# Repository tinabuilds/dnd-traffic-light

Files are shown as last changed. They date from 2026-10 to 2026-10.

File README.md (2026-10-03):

# Do Not Disturb Desk Traffic Light

A small 3D-printed traffic light that sits on my desk and tells the people at home whether they can come talk to me.

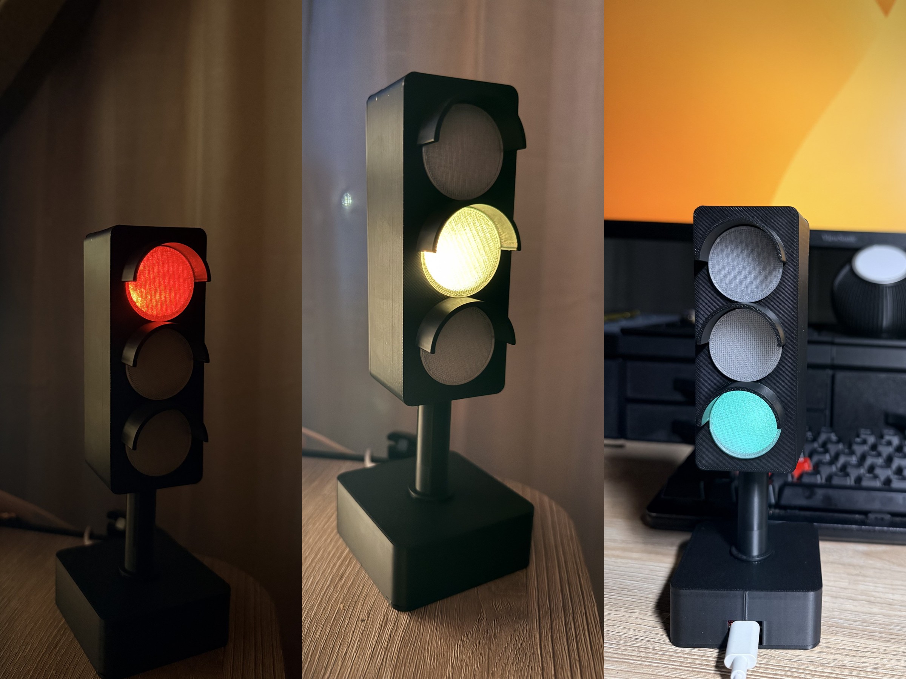
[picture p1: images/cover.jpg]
Red, yellow and green


| Color | Meaning |
|---|---|
| 🔴 Red | On a call, or audio is playing in my headphones. Don't come in. |
| 🟡 Yellow | In a focus block. Interrupt only if it matters. Blinks in the last 5 minutes. |
| 🟢 Green | Come find me. |
| Off | I'm away from the computer. |

The light only shows what the other person *can't* see. Just sitting at the computer isn't yellow, because they can see that.

## How it works

The board doesn't make any decisions. The computer works out the color and sends one letter over USB serial, about once a second:

| Letter | Effect |
|---|---|
| `R` | red |
| `Y` | yellow |
| `B` | blinking yellow |
| `G` | green |
| `O` | off |
| `?` | board replies `traffic-light` (to find the right serial port) |

If nothing arrives for 15 seconds, the light turns itself off. That way it never gets stuck on an old color when the laptop sleeps or the cable comes out.

Because all the rules live on the computer, you can change them without reflashing.

### The rules I use (checked in order)

1. **Red**: manual red (keyboard shortcut), the microphone is in use (dictation apps don't count), or real sound is coming out of the headphones
2. **Off**: no keyboard or mouse input for 5 minutes
3. **Yellow**: inside a focus block (a Google Calendar Focus Time event, or one started from a shortcut)
4. **Green**: everything else

My own sender script is tied to my personal setup, so it isn't here. The protocol is simple enough that a few lines will drive the light:

```python
# pip install pyserial
import serial, time
port = serial.Serial("/dev/cu.usbmodem1101", 115200)   # your port will differ
while True:
    port.write(b"G")      # replace with your own logic
    time.sleep(1)
```

## Parts

- Seeed Studio XIAO ESP32-C3
- 5 LEDs of WS2812B strip, 60 LEDs/m, **one uncut piece** (LEDs 0 / 2 / 4 light green / yellow / red; 1 and 3 stay off)
- 3 short wires, USB-C cable
- Filament: clear PETG for the lenses, black PLA for the body

Wiring: strip DIN → **D1**, 5V → 5V, GND → GND. Don't use D0: it's a boot strapping pin, and a strip on it can stop the board from booting.

Thread the wires through the pole **before** you solder.

| Strip on the back cover | Strip going into the housing | XIAO soldered |
|---|---|---|
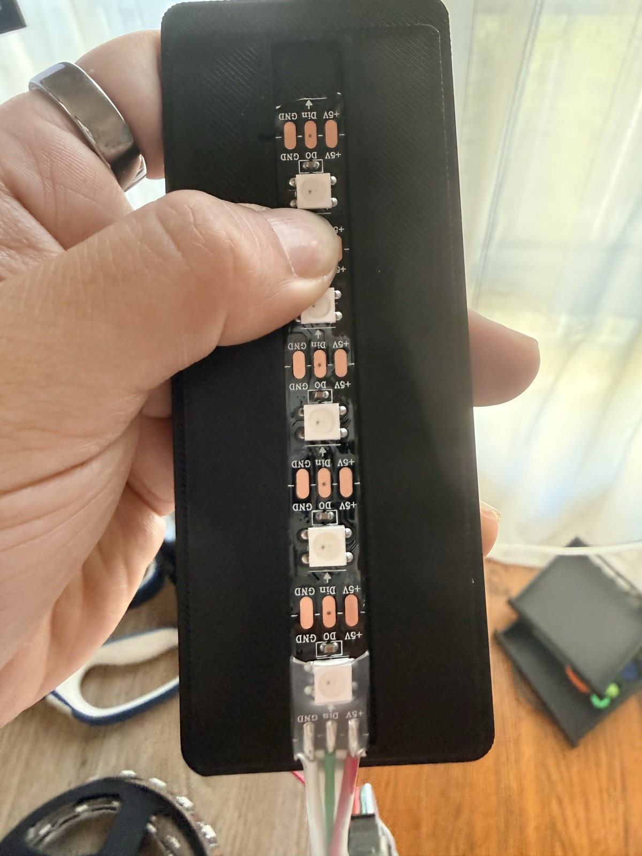
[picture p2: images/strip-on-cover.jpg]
Strip on the back cover
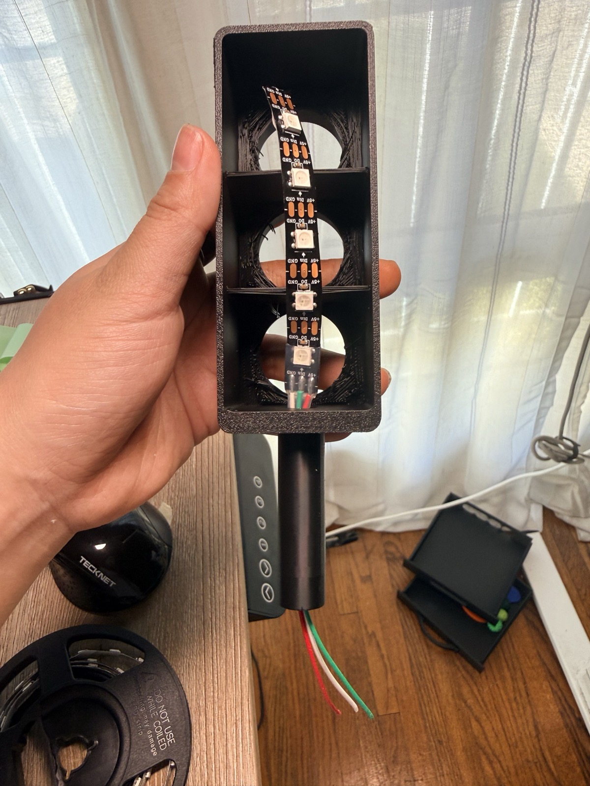
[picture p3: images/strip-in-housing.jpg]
Strip going into the housing
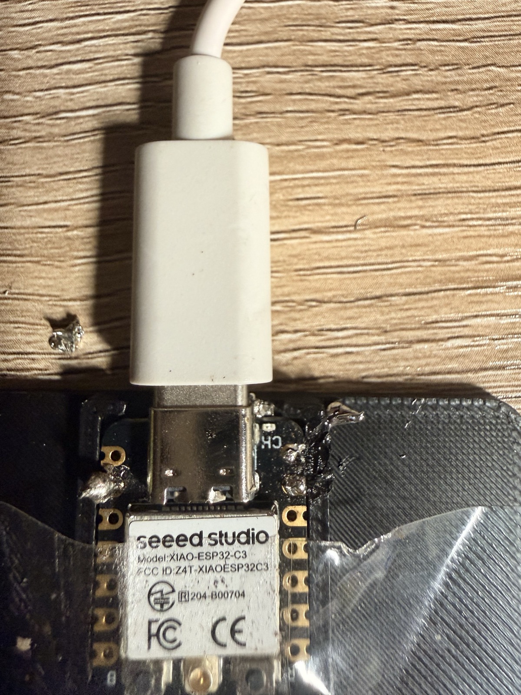
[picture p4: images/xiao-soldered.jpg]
XIAO soldered
|  |  |  |

The strip sits in a channel on the inside of the back cover, so the LEDs line up with the lenses on their own.

## Firmware

[`firmware/traffic_light_fw/traffic_light_fw.ino`](firmware/traffic_light_fw/traffic_light_fw.ino). Needs the Adafruit NeoPixel library.

```bash
arduino-cli compile --fqbn esp32:esp32:XIAO_ESP32C3 firmware/traffic_light_fw
arduino-cli upload  --fqbn esp32:esp32:XIAO_ESP32C3 -p <port> firmware/traffic_light_fw
```

On power-up it flashes green, yellow, red once, so you can check the LEDs line up.

## 3D model

[`cad/traffic_light.scad`](cad/traffic_light.scad) is the full OpenSCAD source. Export each part:

```bash
cd cad
for p in housing cover lenses pole base plate; do
  openscad -D "part=\"$p\"" -o "$p.stl" traffic_light.scad
done
```

No supports needed. Print the lenses in clear PETG and everything else in black PLA. The pole screws into the base; the other parts push in and hold on crush ribs, so no glue.

## License

[CC BY-NC 4.0](https://creativecommons.org/licenses/by-nc/4.0/) — free to build, remix and share with credit, as long as it is not for commercial use (no selling prints, kits or files).

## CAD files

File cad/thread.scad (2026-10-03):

// Single-start round thread: an off-center circle extruded with a twist.
// The same module makes the bolt and the hole; only the radius differs (hole = r + clearance per side).
// Tested: r = 8, offset 0.6 (1.2 mm thread depth), pitch 3, hole +0.3 per side. Prints standing, no supports.
module thread(r, l, e = 0.6, pitch = 3)
    linear_extrude(l, twist = -360 * l / pitch, slices = ceil(l / pitch * 36), convexity = 4)
        translate([e, 0]) circle(r = r - e, $fn = 64);

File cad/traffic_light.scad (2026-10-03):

// Mini desk traffic light for a WS2812B strip (60 LED/m) + Seeed XIAO ESP32-C3. Units: mm.
// Export: openscad -D 'part="housing"' -o housing.stl traffic_light.scad
// Parts: housing, cover, lenses, pole, base, plate, assembly (preview only)
//
// Joints (v2, after the first print came out loose):
//   pole -> base   screws in (same round thread as the scrunchie post, tested good); a collar on the pole stops it
//   pole -> housing, cover -> housing, plate -> base   push in and hold on crush ribs:
//     thin triangular ribs that squash on the way in, so the fit doesn't depend on hitting an exact clearance.
//     No printed snap bumps: two broke on the claw-clip rack.
//
// One uncut 5-LED piece of strip runs up the back cover. At 60 LED/m the pitch is
// 16.67 mm, so LEDs 0 / 2 / 4 land exactly on the three lenses; 1 and 3 stay off.

part = "assembly";

PITCH = 1000 / 60;
SP = 2 * PITCH;                  // lens spacing = 33.33
W = 44;  H = 112;  D = 34;       // housing outer (x, y, z); z = depth, front at z = D
WALL = 2;  FRONT = 2.4;  FLOOR = 6;  R = 4;
LENS_Y = [FLOOR + 16.67, FLOOR + 16.67 + SP, FLOOR + 16.67 + 2 * SP];
HOLE = 28;  LENS_D = 31;  LENS_T = 1.2;  FIT = 0.4;
VISOR_R = 17;  VISOR_T = 1.8;  VISOR_L = 12;
POLE_OD = 14;  POLE_ID = 9;  POLE_VIS = 43;  SOCKET = 5;  PFIT = 0.3;   // POLE_VIS = pole showing between collar and housing
THREAD_R = 8;  THREAD_E = 0.6;  THREAD_PITCH = 3;  THREAD_L = 10;  THREAD_FIT = 0.3;   // not PITCH: that name is the LED pitch above
COLLAR_D = 20;  COLLAR_H = 2;  BOSS_D = 24;
RIB = 0.35;      // how far a crush rib stands proud of the part's nominal surface (clearances here are 0.15 per side)
LIP = 3;         // cover lip depth into the housing. Keep LIP + LED height (~1.6) under the dividers' start (z = 6)
BW = 64;  BH = 24;  BWALL = 2.4;  BTOP = 3;  BR = 6;
PLATE_FL = 1.6;  PLATE_LIP = 3;   // bottom plate: flange under the base's bottom edge + lip that pushes in on crush ribs
XIAO = [21, 17.8];  USB_SLOT = [14, 11];   // cradle size checked on the print: XIAO drops in exactly
STRIP_W = 10.5;
$fn = 72;

use <thread.scad>

// crush rib: triangular, standing on a face that points along +x, height h along z, chamfered at the top
module rib(h) {
  hull() {
    translate([-0.2, -0.6, 0]) cube([0.2, 1.2, h]);
    translate([0, -0.01, 0]) cube([RIB, 0.02, h - 0.6]);
  }
}

module rbox(x, y, z, r) {             // rounded in the x-y plane, height z
  linear_extrude(z) offset(r) offset(-r) square([x, y], center = true);
}

// ---------- housing (print back-side down, visors pointing up) ----------
module housing() {
  difference() {
    union() {
      translate([0, H/2, 0]) rbox(W, H, D, R);
      for (y = LENS_Y) visor(y);
    }
    // hollow, open at the back
    translate([0, (H + FLOOR - WALL)/2, -1]) rbox(W - 2*WALL, H - FLOOR - WALL, D - FRONT + 1, R - WALL);
    for (y = LENS_Y) {
      translate([0, y, D - FRONT - 1]) cylinder(d = HOLE, h = FRONT + 2);
      translate([0, y, D - FRONT - 0.01]) cylinder(d = LENS_D + FIT, h = LENS_T + 0.01);
    }
    // pole socket in the thick floor, then wire hole into the housing
    translate([0, -1, D/2]) rotate([-90, 0, 0]) cylinder(d = POLE_OD + PFIT, h = SOCKET + 1);
    translate([0, 0, D/2]) rotate([-90, 0, 0]) cylinder(d = POLE_ID, h = FLOOR + 1);
  }
  // light dividers, stop short of the back so the strip can pass
  for (y = [(LENS_Y[0] + LENS_Y[1])/2, (LENS_Y[1] + LENS_Y[2])/2])
    translate([-(W - 2*WALL)/2, y - 0.8, 6]) cube([W - 2*WALL, 1.6, D - FRONT - 6]);
}

module visor(y) {
  translate([0, y, D]) difference() {
    cylinder(r = VISOR_R, h = VISOR_L);
    translate([0, 0, -1]) cylinder(r = VISOR_R - VISOR_T, h = VISOR_L + 2);
    translate([-VISOR_R - 1, -2*VISOR_R - 1, -1]) cube([2*VISOR_R + 2, 2*VISOR_R + 1, VISOR_L + 2]);
  }
}

// ---------- back cover (print flange down) ----------
module cover() {
  iw = W - 2*WALL - 0.3;  ih = H - FLOOR - WALL - 0.3;
  cy = (H + FLOOR - WALL)/2;  top = 1.6 + LIP;
  difference() {
    union() {
      translate([0, H/2, 0]) rbox(W, H, 1.6, R);
      translate([0, cy, 1.6]) rbox(iw, ih, LIP, R - WALL);
      // crush ribs: 3 on each long side, 1 on each short side
      for (sx = [-1, 1], dy = [-ih/3, 0, ih/3]) translate([sx * iw/2, cy + dy, 1.6]) rotate([0, 0, sx > 0 ? 0 : 180]) rib(LIP);
      for (sy = [-1, 1]) translate([0, cy + sy * ih/2, 1.6]) rotate([0, 0, sy > 0 ? 90 : -90]) rib(LIP);
    }
    // strip channel on the inside, with a tick where LED 0 goes
    translate([-STRIP_W/2, FLOOR + 2, top - 0.8]) cube([STRIP_W, H - FLOOR - 6, 1]);
    translate([STRIP_W/2 - 0.5, LENS_Y[0] - 0.5, top - 1.6]) cube([3, 1, 2]);
  }
}

// ---------- lenses (clear filament, print flat) ----------
module lenses() {
  for (i = [0:2]) translate([i * (LENS_D + 3), 0, 0]) cylinder(d = LENS_D, h = LENS_T);
}

// ---------- pole (print standing, thread down) ----------
// z = 0 thread tip | THREAD_L collar | + COLLAR_H tube | top SOCKET mm has crush ribs for the housing
POLE_TOP = THREAD_L + COLLAR_H + POLE_VIS + SOCKET;
module pole() {
  difference() {
    union() {
      difference() {   // thread, tip chamfered so it starts easily
        thread(THREAD_R, THREAD_L, THREAD_E, THREAD_PITCH);
        translate([0, 0, -1]) difference() { cylinder(r = THREAD_R + 1, h = 2); cylinder(r1 = THREAD_R - 1, r2 = THREAD_R, h = 2); }
      }
      translate([0, 0, THREAD_L]) cylinder(d = COLLAR_D, h = COLLAR_H);
      translate([0, 0, THREAD_L + COLLAR_H - 0.01]) cylinder(d = POLE_OD, h = POLE_VIS + SOCKET + 0.01);
      for (a = [0:60:359]) rotate(a) translate([POLE_OD/2, 0, POLE_TOP - SOCKET]) rib(SOCKET);
    }
    translate([0, 0, -1]) cylinder(d = POLE_ID, h = POLE_TOP + 2);
  }
}

// ---------- base (print upside down: top on the bed, open bottom up) ----------
// Base frame: z = 0 is the top face, z = BH the open bottom. Back wall is -y.
module base() {
  difference() {
    union() {
      rbox(BW, BW, BH, BR);
    }
    translate([0, 0, BTOP]) rbox(BW - 2*BWALL, BW - 2*BWALL, BH, BR - BWALL);
    // threaded hole for the pole, chamfered mouth on the top face
    translate([0, 0, -0.01]) thread(THREAD_R + THREAD_FIT, THREAD_L + 1, THREAD_E, THREAD_PITCH);
    translate([0, 0, -0.01]) cylinder(r1 = THREAD_R + THREAD_FIT + 0.6, r2 = THREAD_R + THREAD_FIT, h = 0.6);
    // USB-C notch in the back wall, open at the bottom edge
    translate([-USB_SLOT[0]/2, -BW/2 - 1, BH - USB_SLOT[1]]) cube([USB_SLOT[0], BWALL + 2, USB_SLOT[1] + 1]);
  }
  // boss that carries the thread (open through, the wires come out its bottom)
  difference() {
    cylinder(d = BOSS_D, h = THREAD_L + 1);
    translate([0, 0, -0.01]) thread(THREAD_R + THREAD_FIT, THREAD_L + 1.02, THREAD_E, THREAD_PITCH);
    translate([0, 0, -0.01]) cylinder(r1 = THREAD_R + THREAD_FIT + 0.6, r2 = THREAD_R + THREAD_FIT, h = 0.6);
  }
}

// ---------- bottom plate with XIAO cradle (print flange down, cradle up) ----------
// The flange matches the base's footprint and stops against its bottom edge; the lip pushes in and holds on crush ribs.
// USB end of the board faces -y (the base's back wall, where the USB notch is).
module plate() {
  pw = BW - 2*BWALL - 0.3;
  difference() {
    union() {
      rbox(BW, BW, PLATE_FL, BR);
      translate([0, 0, PLATE_FL]) rbox(pw, pw, PLATE_LIP, BR - BWALL);
      for (a = [0:90:270], d = [-pw/4, pw/4]) rotate(a) translate([pw/2, d, PLATE_FL]) rib(PLATE_LIP);   // 2 per side
    }
    // gap in the lip under the USB notch, so the plug's overmold clears it
    translate([-(USB_SLOT[0] + 1)/2, -pw/2 - 1, PLATE_FL]) cube([USB_SLOT[0] + 1, 4, PLATE_LIP + 1]);
  }
  y0 = -pw/2;                                   // inner face of the back wall
  translate([0, y0 + (XIAO[0] + 3)/2, PLATE_FL + PLATE_LIP]) difference() {
    rbox(XIAO[1] + 4, XIAO[0] + 3, 2.5, 1);
    translate([0, 0, 3.5]) cube([XIAO[1] + 0.4, XIAO[0] + 0.4, 5], center = true);
    translate([0, -XIAO[0]/2, 3.5]) cube([XIAO[1] - 4, 6, 5], center = true);   // open USB end
  }
}

// ---------- assembly preview ----------
module assembly() {
  color("#222") translate([0, 0, BH]) rotate([180, 0, 0]) base();
  color("#222") translate([0, 0, -PLATE_FL]) rotate([0, 0, 180]) plate();
  color("#333") translate([0, 0, BH - THREAD_L]) pole();   // collar sits on the base's top face
  hz = BH - THREAD_L + POLE_TOP - SOCKET;        // housing bottom height
  translate([0, D/2, hz]) rotate([90, 0, 0]) {
    color("#1b1b1b") housing();
    for (i = [0:2]) color(["#639922", "#EF9F27", "#E24B4A"][i], 0.9)
      translate([0, LENS_Y[i], D - FRONT]) cylinder(d = LENS_D, h = LENS_T);
    color("#1b1b1b") translate([0, 0, -1.6]) cover();
  }
}

if (part == "housing") housing();
else if (part == "cover") cover();
else if (part == "lenses") lenses();
else if (part == "pole") pole();
else if (part == "base") base();
else if (part == "plate") plate();
else assembly();

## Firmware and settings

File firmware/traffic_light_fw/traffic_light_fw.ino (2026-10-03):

// Do Not Disturb desk traffic light: Seeed XIAO ESP32-C3 + 5 LEDs of WS2812B strip (60 LEDs/m), DIN on D1.
// The board makes no decisions. It only listens for single letters on USB serial,
// so you can change the rules on the computer side without reflashing.
//
//   R red   Y yellow   B blinking yellow   G green   O off   ? replies "traffic-light"
//
// Send the current letter about once a second as a heartbeat. If nothing arrives for 15 seconds,
// the light turns itself off, so it never gets stuck on an old color when the laptop sleeps,
// the sender crashes or the cable comes out.
//
// The strip runs up from the bottom: LEDs 0 / 2 / 4 sit behind green / yellow / red, 1 and 3 stay off.
// Build: arduino-cli compile --fqbn esp32:esp32:XIAO_ESP32C3 (USB CDC is on by default on this board.
// Don't add CDCOnBoot=cdc: on the XIAO that value turns it off.)
// Library: Adafruit NeoPixel. WiFi is never included, so it never starts.
#include <Adafruit_NeoPixel.h>

const int PIN = D1;   // not D0: D0 is GPIO2, a boot strapping pin, and a strip on it can stop the board from booting
const int N = 5;
const int GREEN = 0, YELLOW = 2, RED = 4;
const uint8_t BRIGHT = 60;              // 0-255
const unsigned long TIMEOUT_MS = 15000;

Adafruit_NeoPixel strip(N, PIN, NEO_GRB + NEO_KHZ800);
char mode = 'O';
unsigned long lastRx = 0;

void show(int idx, uint32_t color) {
  strip.clear();
  if (idx >= 0) strip.setPixelColor(idx, color);
  strip.show();
}

void render() {
  bool blinkOn = (millis() / 500) % 2 == 0;
  switch (mode) {
    case 'R': show(RED, strip.Color(255, 0, 0)); break;
    case 'Y': show(YELLOW, strip.Color(255, 140, 0)); break;
    case 'B': show(blinkOn ? YELLOW : -1, strip.Color(255, 140, 0)); break;
    case 'G': show(GREEN, strip.Color(0, 255, 40)); break;
    default:  show(-1, 0);
  }
}

void setup() {
  setCpuFrequencyMhz(80);
  Serial.begin(115200);
  strip.begin();
  strip.setBrightness(BRIGHT);
  // Power-on self test: green, yellow, red for half a second each, so you know right away the LEDs line up
  int order[3] = {GREEN, YELLOW, RED};
  uint32_t colors[3] = {strip.Color(0, 255, 40), strip.Color(255, 140, 0), strip.Color(255, 0, 0)};
  for (int i = 0; i < 3; i++) { show(order[i], colors[i]); delay(500); }
  show(-1, 0);
}

void loop() {
  while (Serial.available()) {
    char c = Serial.read();
    if (c == 'R' || c == 'Y' || c == 'B' || c == 'G' || c == 'O') { mode = c; lastRx = millis(); }
    else if (c == '?') Serial.println("traffic-light");   // handshake, to find which serial port is the light
  }
  if (mode != 'O' && millis() - lastRx > TIMEOUT_MS) mode = 'O';
  render();
  delay(20);
}

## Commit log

2026-10-03 Do Not Disturb desk traffic light: firmware, OpenSCAD model, README
    [thread.scad, traffic_light.scad]
2026-10-03 Switch license from MIT to CC BY-NC 4.0
